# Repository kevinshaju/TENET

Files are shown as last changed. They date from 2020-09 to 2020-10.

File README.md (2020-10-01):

# __TENET__
WIRELESS DEVELOPMENT BOARD DESIGN

TENET is development board specifically designed for beginners and enthusiasts in the field of IoT and Robotics. At the heart of the board is the NINA-B302 microcontroller unit. The board also features the ESP-12F wireless chip for wireless connectivity. Incase if you're wondering how is it any different from other boards out there, then have a closer look at the design. TENET has an inbuilt DRV8833 motordriver which can be used to connect upto 2 motors without the need for any external shields. The board also has a Li-Po charging unit that can be used to power the board using a single cell Li-Po battery, which will come in handy while prototyping your next wireless robot.

The board also has quite a few sensors that you might need for your integrated Iot project. The details of all the features of the board are provided below:

1) 16 GPIO Headers
2) LSM9DS1-iNEMO Inertial Module
3) DRV8833 dual-H Bridge Motor Driver
4) LPS25HB Pressure Sensor
5) APDS-9960 Digital Proximity, Ambient Light, RGB and Gesture Sensor
6) HTS221 Capacitive digital sensor for relative humidity and temperature
7) ESP-12F WiFi Module

##  *"With TENET the only limit is your own imagination."*

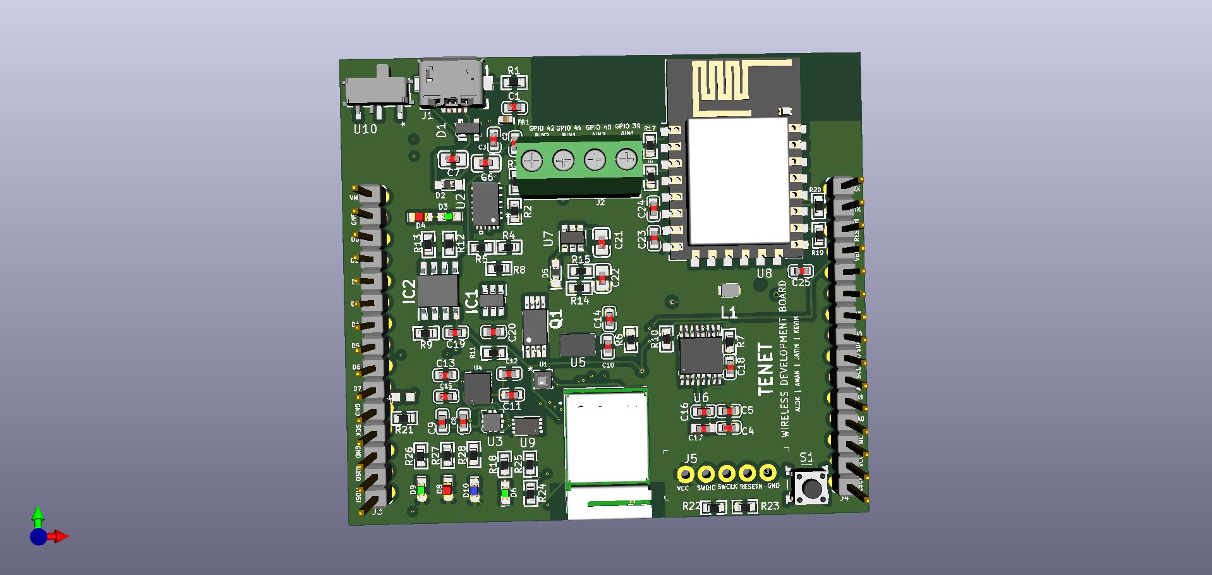
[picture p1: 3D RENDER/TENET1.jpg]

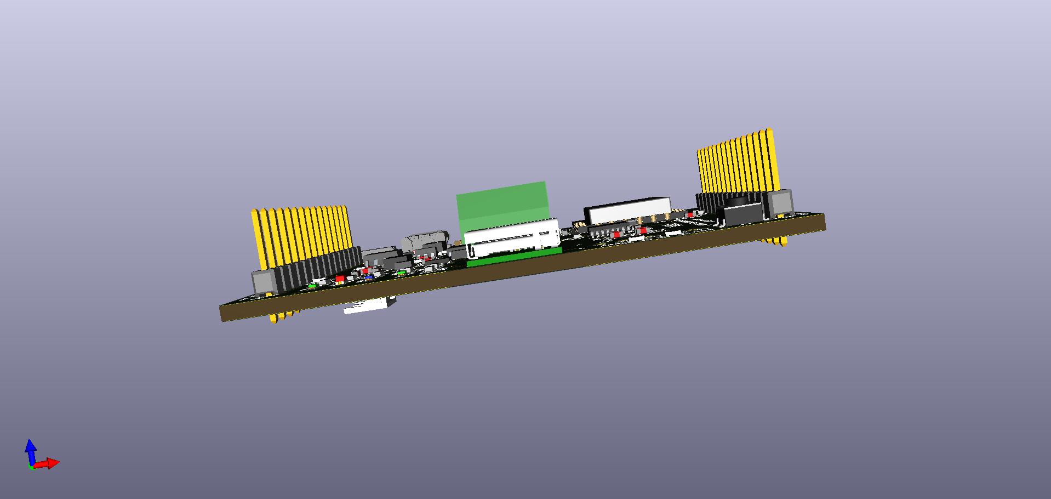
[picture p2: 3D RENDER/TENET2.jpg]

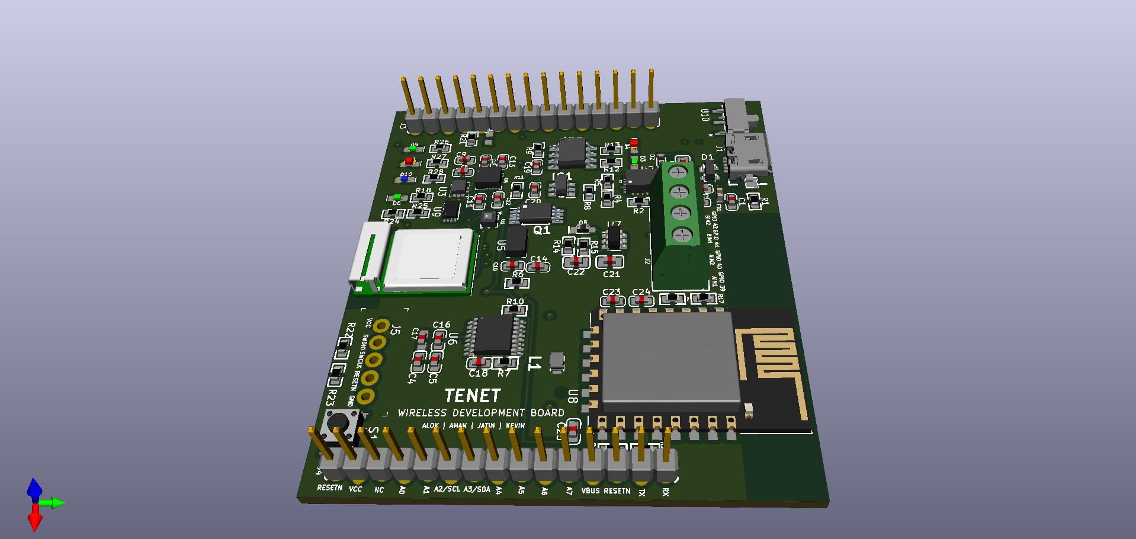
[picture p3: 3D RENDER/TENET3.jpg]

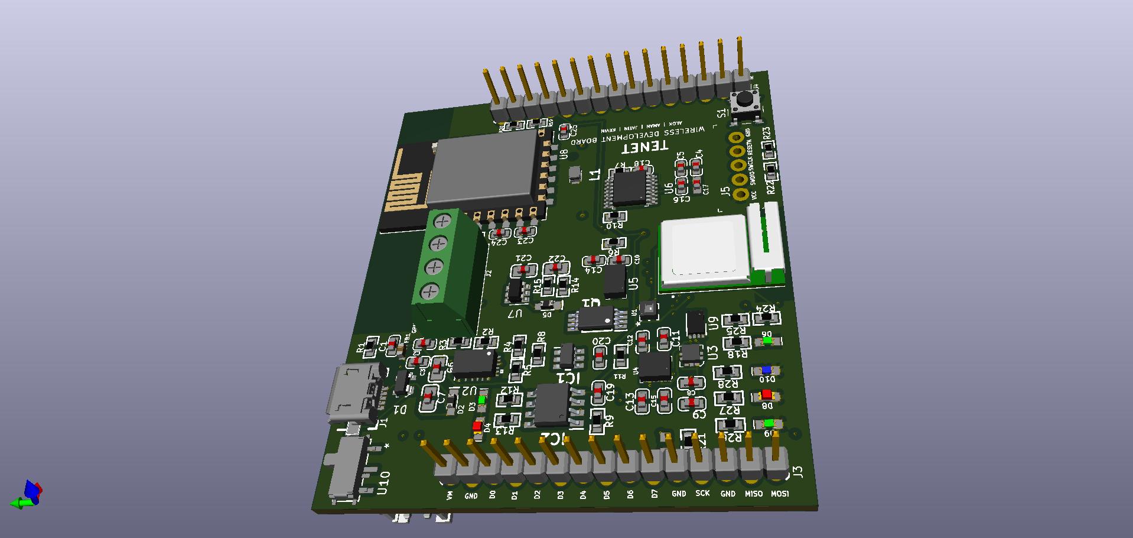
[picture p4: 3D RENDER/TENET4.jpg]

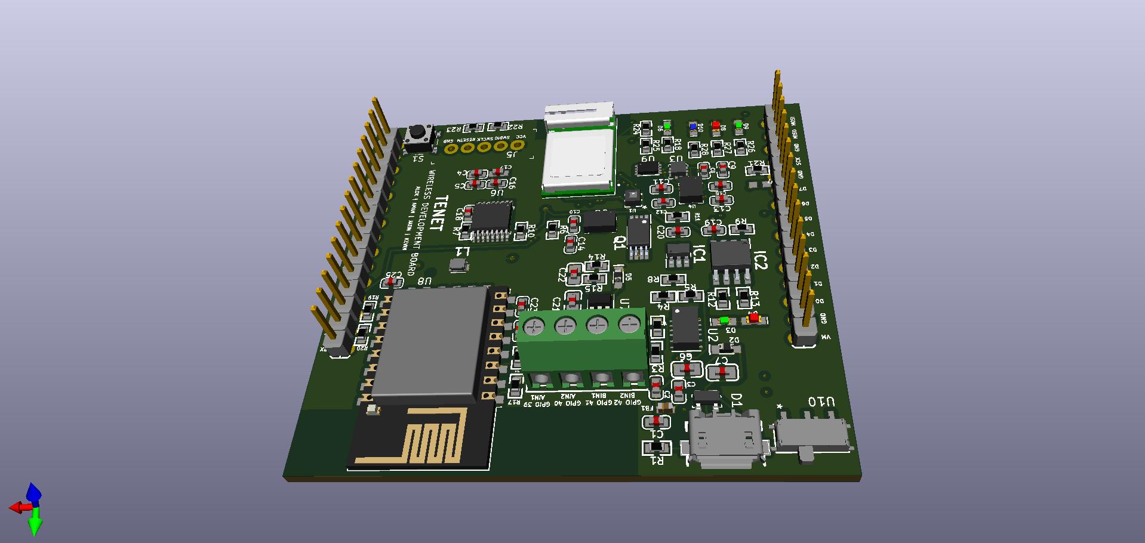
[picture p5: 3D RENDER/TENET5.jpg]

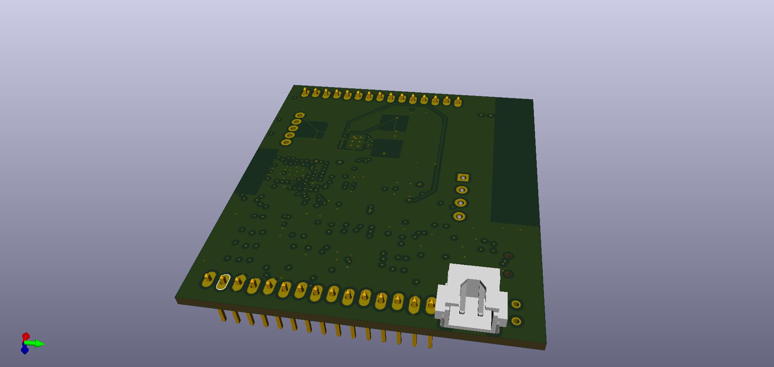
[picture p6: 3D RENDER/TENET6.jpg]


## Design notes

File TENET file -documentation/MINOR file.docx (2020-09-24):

a. Objective
b. Component required (rating and specification of each component)
c. Principle of working
d. Block diagram and description
e. Circuit diagram
f. Description of circuit and components
g. Advantage and disadvantage
h. application
i. result(photo)
j. Problem during designing
k. Cost of the project

Main processor used is nrf52840 is NINA B3X package

KEY FEATURES

Bluetooth 5 ready multi-protocol radio

- 2Mbps

- Long range

- Advertising extensions

- Improved coexistence (CSA #2)

IEEE 802.15.4 radio support

- Thread

- Zigbee

32-bit ARM Cortex-M4F @ 64MHz

Up to 111 dB link budget for Bluetooth long range mode Full-speed 12Mbs USB controller NFC Tag-A Software stacks available as downloads Application development independent of protocol stack Programmable output power from +8dBm to -20dBm -96dBm Sensitivity for Bluetooth low energy On-air compatible with nRF51, nRF24L and nRF24AP Series Arm CryptoCell CC310 crytographic security module High-precision RSSI Wide supply voltage range + 1.7V to 5.5V QSPI/SPI/2-wire/I²S/PDM/QDEC Programmable Peripheral Interface - PPI High speed SPI interface 32MHz Quad SPI interface 32MHz EasyDMA for all digital interfaces RAM mapped FIFO using EasyDMA 12bit/200K SPS ADC 128 bit AES/ECB/CCM/AAR co-processor Single-ended antenna output (on-chip balun) On-chip DC-DC buck converter Quadrature demodulator Regulated supply for external components up to 25mA

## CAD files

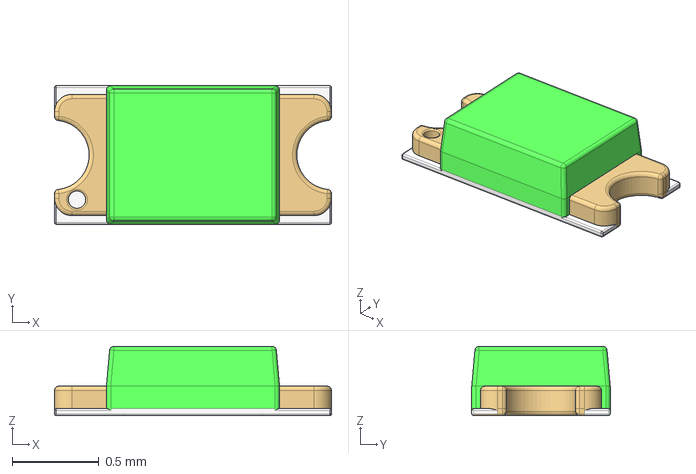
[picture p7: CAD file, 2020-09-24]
3D Libraries/LED Green SMD 0603 Würth 150060BS55040.stp
1.60 x 0.8 x 0.4 mm

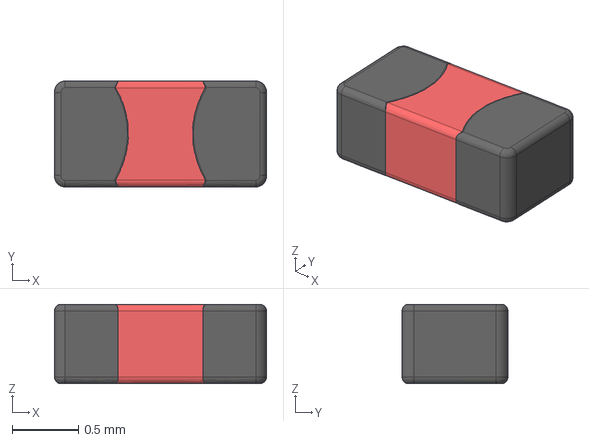
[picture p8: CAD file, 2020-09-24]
3D Libraries/Ceramic CAP0603.stp
1.60 x 0.8 x 0.6 mm

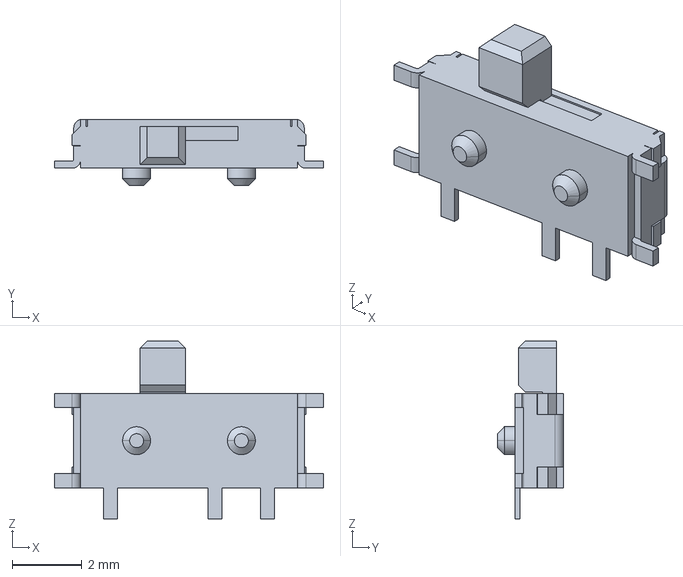
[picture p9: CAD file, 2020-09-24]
3D Libraries/c-1437575-2-b-3d.stp
7.70 x 1.90 x 5.09 mm

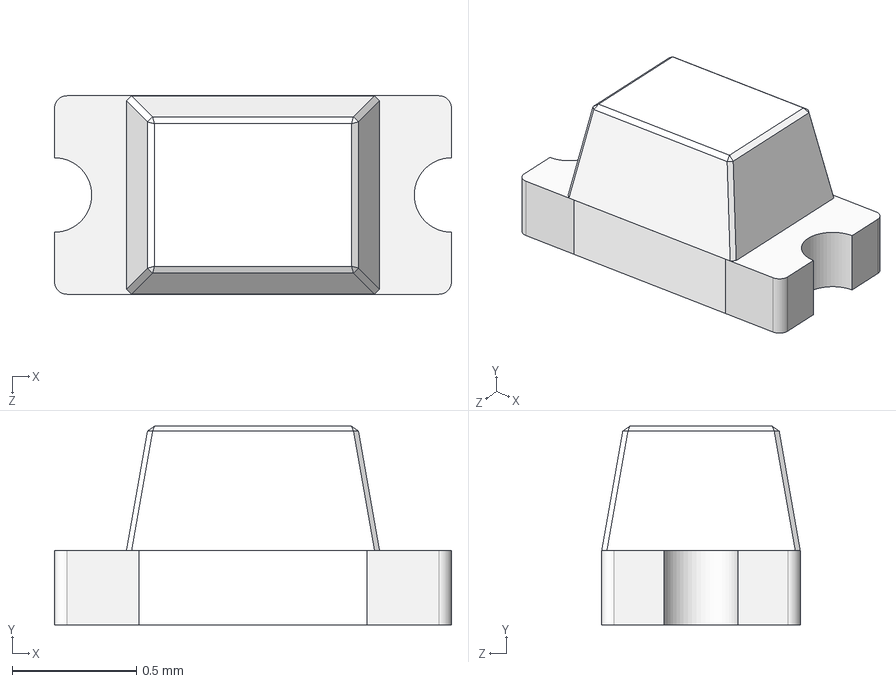
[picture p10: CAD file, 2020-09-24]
3D Libraries/0603 Chip SMD LED (1.6x0.8mm).STEP
1.60 x 0.8 x 0.8 mm

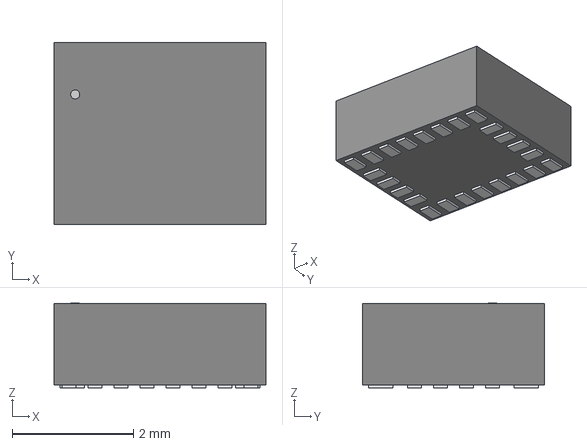
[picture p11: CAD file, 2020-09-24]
3D Libraries/LGA-24_3X3P5X1_STM-L.step
3.50 x 3.00 x 1.40 mm

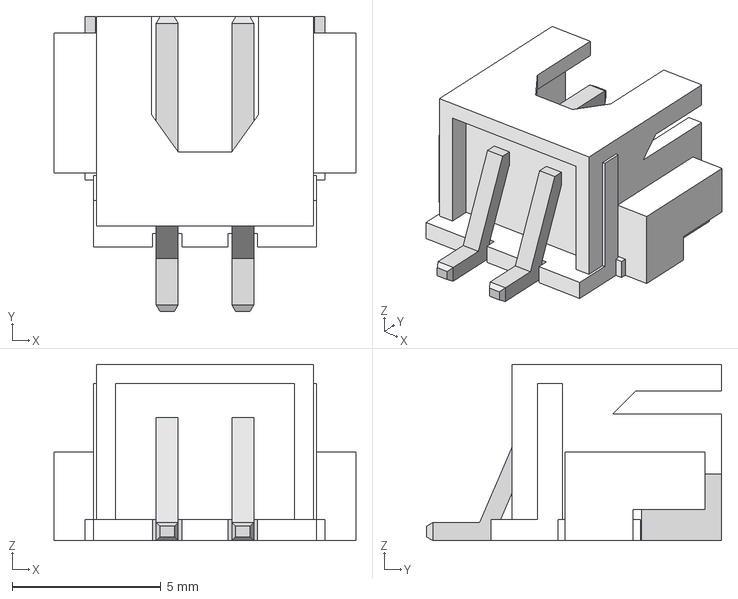
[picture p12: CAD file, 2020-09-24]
3D Libraries/JST - XH - SMD (R) - 2Pin - 2.54mm.stp
10.1 x 9.91 x 5.92 mm

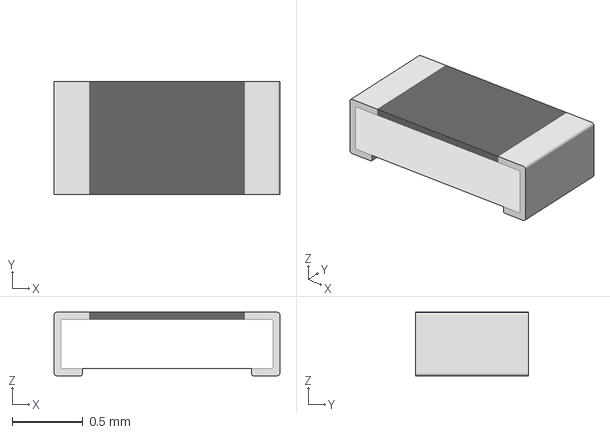
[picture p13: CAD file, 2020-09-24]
3D Libraries/RES0603.igs
1.60 x 0.8 x 0.45 mm

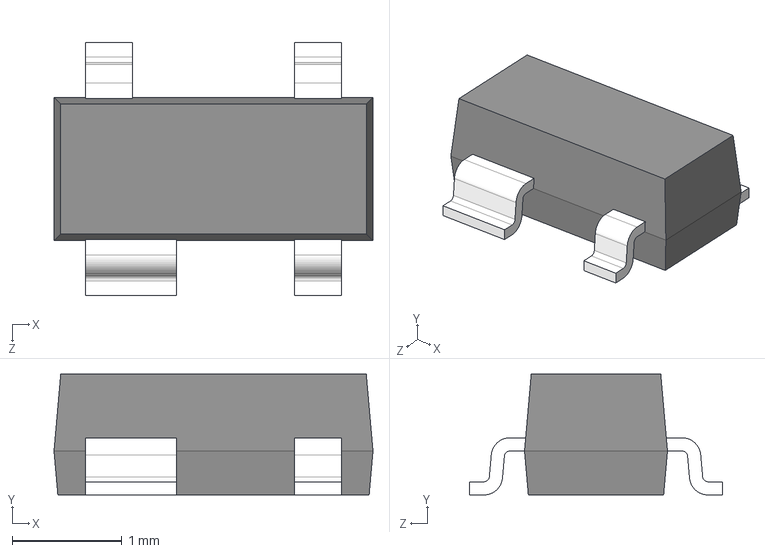
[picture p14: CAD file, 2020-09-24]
3D Libraries/PESD2ETH-AXR--3DModel-STEP-56544.STEP
2.90 x 1.10 x 2.30 mm

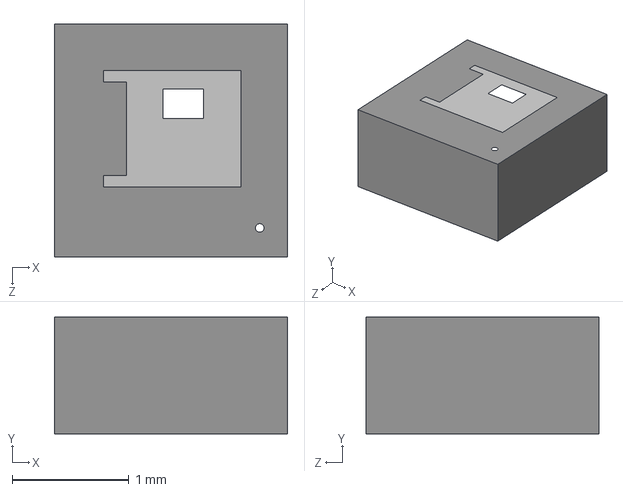
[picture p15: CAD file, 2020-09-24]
3D Libraries/HTS221TR--3DModel-STEP-56544.STEP
2.00 x 1.00 x 2.00 mm

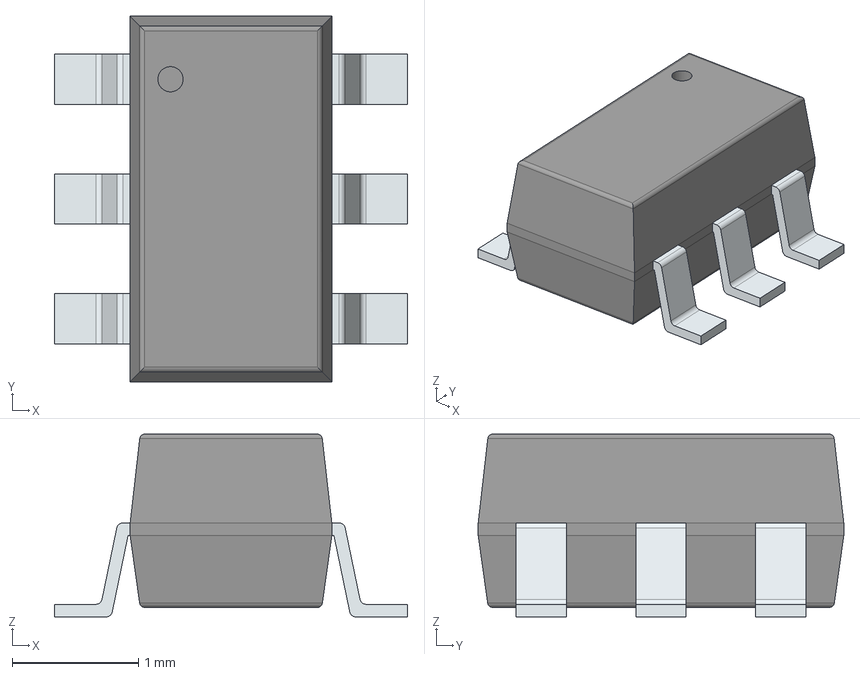
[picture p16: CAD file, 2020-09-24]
3D Libraries/FS312F-G.stp
2.80 x 2.90 x 1.45 mm
PinsArrayLR

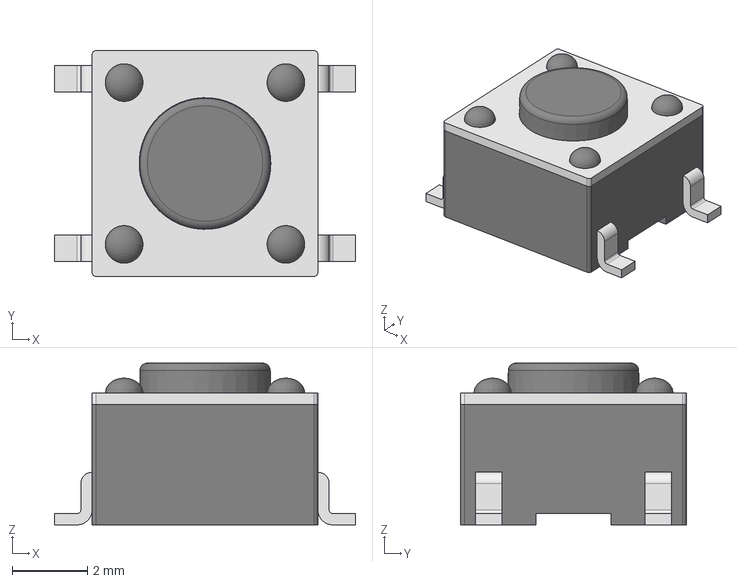
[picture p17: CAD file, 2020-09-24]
3D Libraries/TS6-SMT_H-4.3.step
8.00 x 6.00 x 4.30 mm

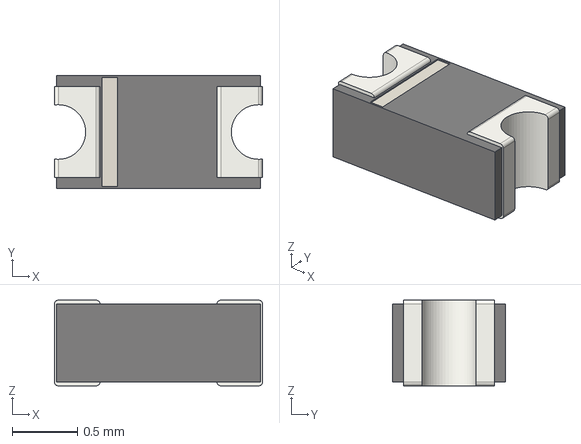
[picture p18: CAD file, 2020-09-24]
3D Libraries/D_0603_1608Metric.step
1.60 x 0.87 x 0.66 mm

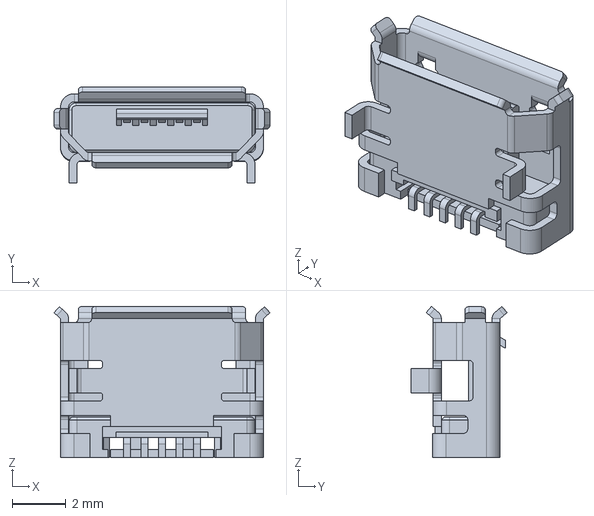
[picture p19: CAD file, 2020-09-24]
3D Libraries/c-2013499-1-e-3d.stp
8.00 x 3.57 x 5.60 mm

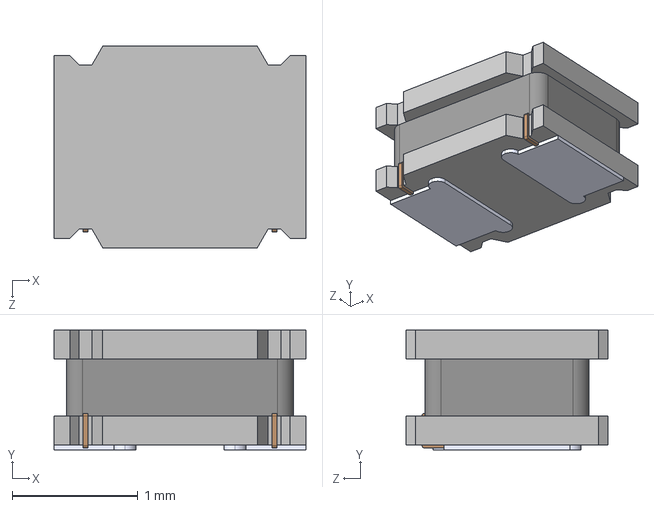
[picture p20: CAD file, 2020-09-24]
3D Libraries/LQH2MPZ220MGRL.STEP
2.00 x 0.95 x 1.60 mm

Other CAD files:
3D Libraries/LED Yellow SMD 0603 Würth 150060YS55040.stp
3D Libraries/LED Blue SMD 0603 Würth 150060BS55040.stp
3D Libraries/FS8205A--3DModel-STEP-56544.STEP
3D Libraries/Ceramic CAP0603.igs
3D Libraries/IND_BLM18_MUR.step
3D Libraries/LED Red SMD 0603 Würth 150060SS55040.stp
3D Libraries/MPM3610.STEP
3D Libraries/NINA-B3x2.STEP
3D Libraries/PWP16_2P31X2P46_TEX-L.step
3D Libraries/Pin Header 1x15 TH Pitch 2.54mm.stp
3D Libraries/QFN_DS-9930-M.step
3D Libraries/Screw Terminal Block 3.5mm 4-way.step
3D Libraries/TP4056-42-ESOP8.stp
3D Libraries/TS6-SMT_H-5.0.step
3D Libraries/c-4-1437565-2-v-3d.stp

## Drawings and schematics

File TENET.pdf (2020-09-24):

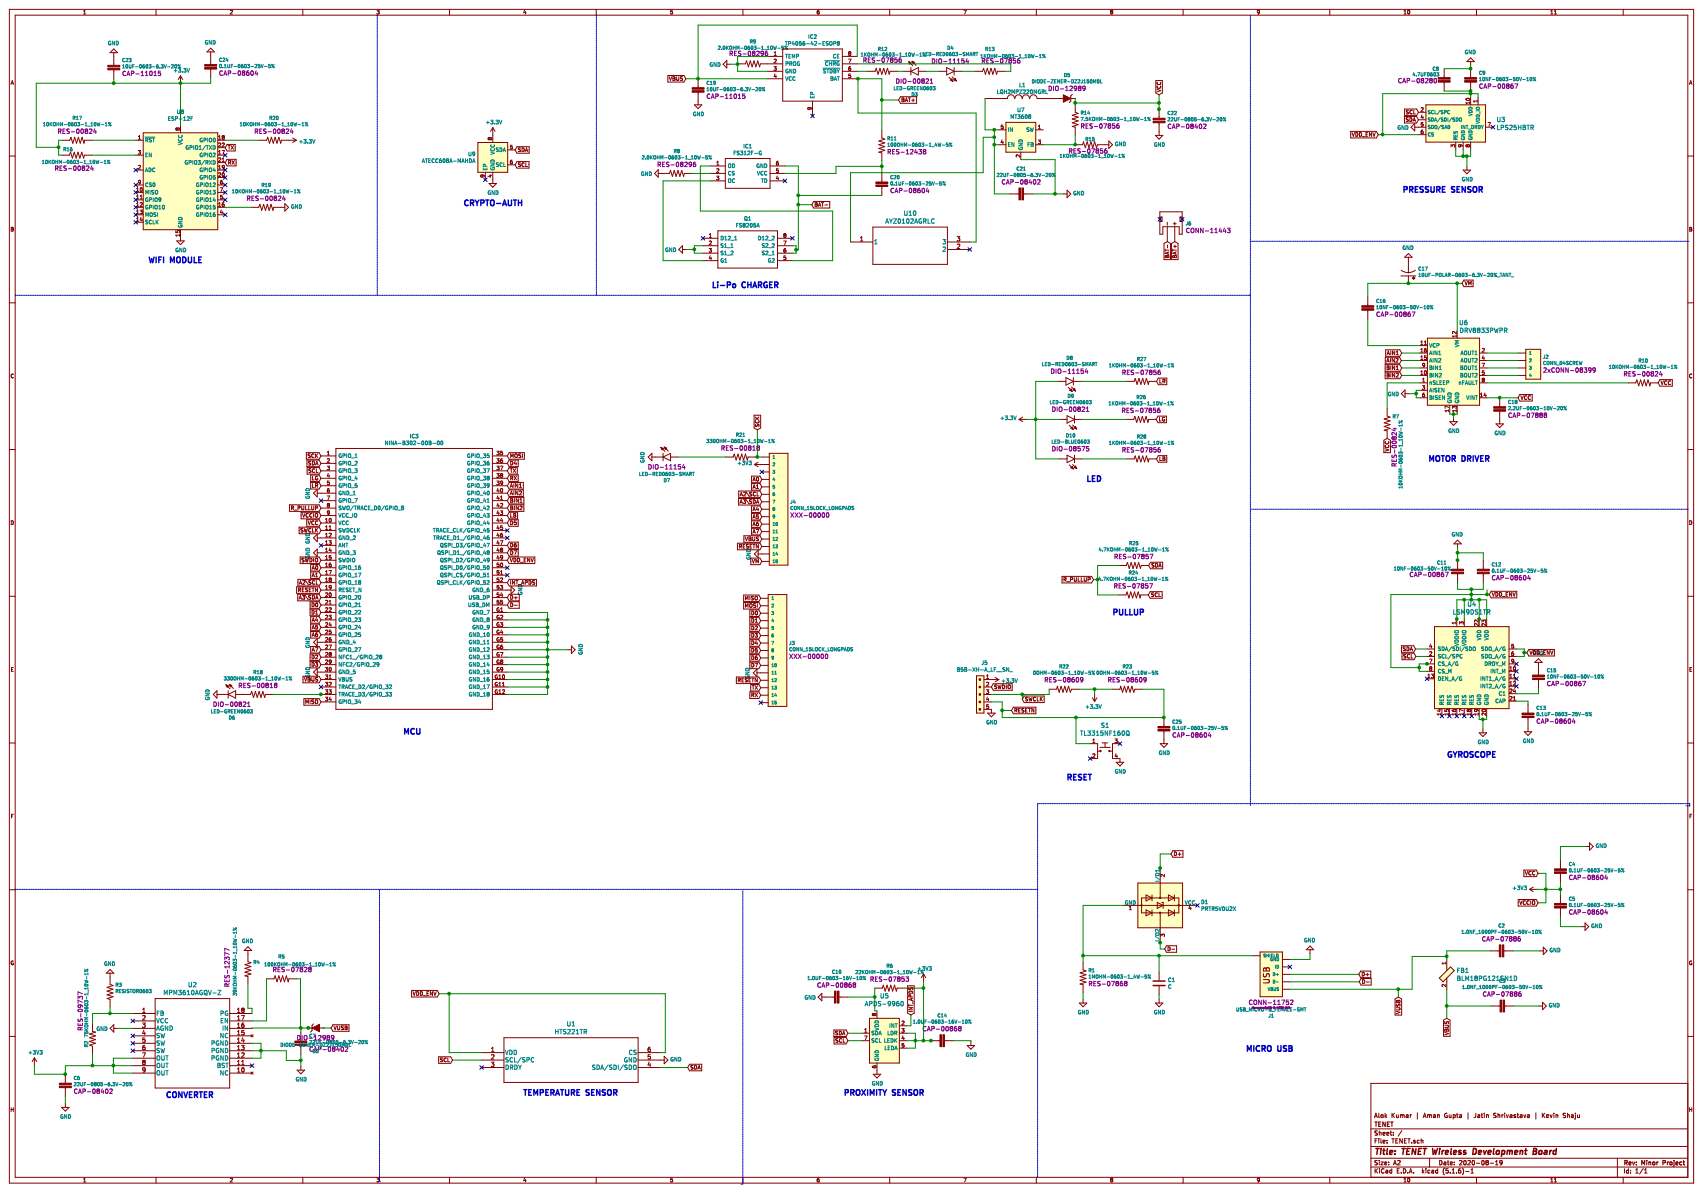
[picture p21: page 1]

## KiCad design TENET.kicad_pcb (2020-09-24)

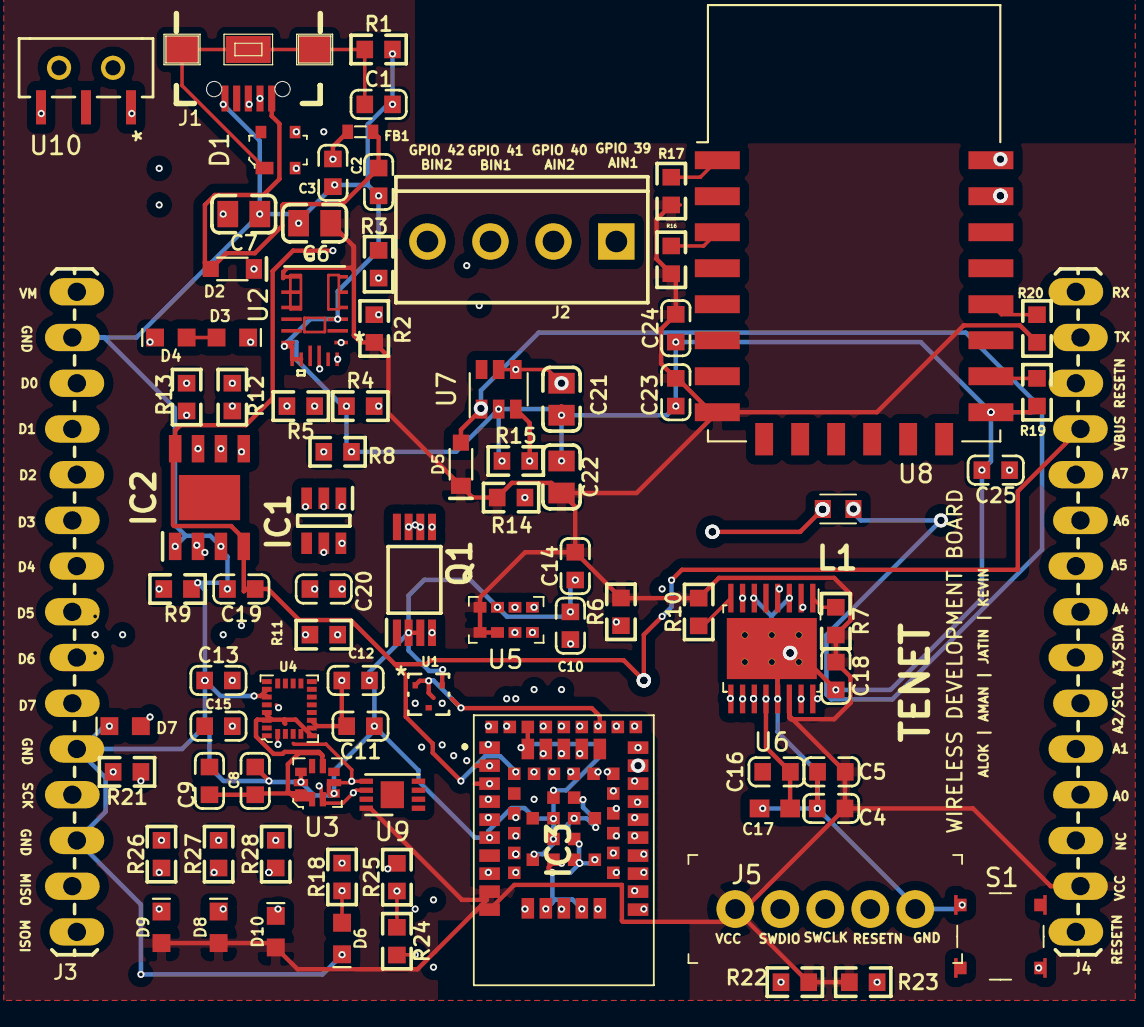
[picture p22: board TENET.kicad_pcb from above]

Board: 4 copper layers, 86 parts (1 on the bottom side), 83 nets.

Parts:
C1, C2, C3, C4, C5, C8, C9, C10, C11, C12, C13, C14, C15, C16, C18, C19, C20, C23, C24, C25: C_0603
C6, C7, C21, C22: C_0805
C17: 0603-POLAR
D1: TO-253-4
D2, D5: PANASONIC_SMINI2-F5-B
D3, D4, D6, D7, D8, D9, D10: LED-0603
FB1: BLM18PG121SN1D; 0603
IC1: SOT95P280X145-6N
IC2: SOIC127P600X175-9N
IC3: NINAB30200B00
J1: USB-B-MICRO-SMD
J2: SCREWTERMINAL-3.5MM-4
J3, J4: 1X15_LOCK_LONGPADS
J5: PinHeader_1x5_P2.5mm_Drill1.1mm
J6: JST-2-SMD
L1: LQH2MCN100K02L
Q1: SOP65P640X120-8N
R1, R2, R3, R4, R5, R6, R7, R8, R9, R10, R11, R12, R13, R14, R15, R16, R17, R18, R19, R20, R21, R22, R23, R24, R25, R26, R27, R28: R_0603
S1: Switch_Tactile_SMD_4.5x4.5mm_TL3315NF160Q
U1: HTS221TR
U2: MPM3610AGQV-Z
U3: LLGA-10_2.5x2.5mm_LPS25HB
U4: LGA-24_3x3.5mm_LSM9DS1
U5: Ambient_Prox_APDS-9960
U6: TSSOP-16-1EP_W4.40mm
U7: SOT-23-6
U8: ESP-12E
U9: DFN-8-1EP_3x2mm_P0.5mm_EP1.3x1.5mm
U10: AYZ0102AGRLC

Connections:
A0: IC3.16, J4.4
A1: IC3.17, J4.5
A2\SCL: IC3.18, J4.6
A3\SDA: IC3.20, J4.7
A4: IC3.23, J4.8
A5: IC3.24, J4.9
A6: IC3.25, J4.10
A7: IC3.27, J4.11
AIN1: IC3.39, U6.16
AIN2: IC3.40, U6.15
BAT+: IC2.5, J6.2, R11.1, U10.3
BAT-: C20.2, IC1.6, J6.1, Q1.6, Q1.7
BIN1: IC3.41, U6.9
BIN2: IC3.42, U6.10
D0: IC3.21, J3.3
D1: IC3.22, J3.4
D2: IC3.28, J3.5
D3: IC3.29, J3.6
D4: IC3.36, J3.7
D5: IC3.44, J3.8
D6: IC3.47, J3.9
D7: IC3.48, J3.10
D+: D1.2, IC3.54, J1.D+
D-: D1.3, IC3.55, J1.D-
GND: C1.2, C2.1, C3.1, C4.1, C5.2, C6.1, C7.1, C8.1, C9.1, C10.2, C11.1, C12.1, C13.1, C14.1, C15.1, C17.-, C18.2, C19.2, C21.1, C22.1, C23.2, C24.1, C25.2, D6.C, D7.C, IC2.1, IC2.3, IC3.6, IC3.12, IC3.14, IC3.26, IC3.30, IC3.53, IC3.G1, IC3.G2, IC3.G3, IC3.G4, IC3.G5, IC3.G6, IC3.G7, IC3.G8, IC3.G9, IC3.G10, IC3.G11, IC3.G12, J1.GND, J3.2, J3.11, J3.13, J5.5, Q1.2, Q1.3, R1.2, R3.1, R4.1, R8.1, R9.1, R15.1, R19.2, S1.4, U1.5, U2.3, U2.12, U2.13, U2.14, U3.3, U3.5, U3.8, U3.9, U4.19, U4.20, U5.6, U6.3, U6.6, U6.13, U6.17, U7.2, U8.15, U9.4
INT_APDS: IC3.52, U5.2
LB: IC3.43, R28.2
LG: IC3.4, R26.2
LR: IC3.5, R27.2
MISO: IC3.34, J3.14
MOSI: IC3.35, J3.15
unnamed: C1.1, D1.1, J1.SHIE, R1.1
unnamed: C7.2, D2.C, R5.2, U2.16
unnamed: C10.1, R6.1, U5.8
unnamed: C13.2, U4.21
unnamed: C15.2, U4.24
unnamed: C16.2, U6.11
unnamed: C20.1, IC1.5, R11.2
unnamed: C21.2, L1.1, U7.4, U7.5, U10.1
unnamed: D3.A, D4.A
unnamed: D3.C, R12.2
unnamed: D4.C, R13.1
unnamed: D5.A, L1.2, U7.1
unnamed: D6.A, R18.1
unnamed: D7.A, R21.1
unnamed: D8.C, R27.1
unnamed: D9.C, R26.1
unnamed: D10.C, R28.1
unnamed: IC1.1, Q1.5
unnamed: IC1.2, R8.2
unnamed: IC1.3, Q1.4
unnamed: IC2.2, R9.2
unnamed: IC2.6, R12.1
unnamed: IC2.7, R13.2
unnamed: IC3.33, R18.2
unnamed: J2.1, U6.2
unnamed: J2.2, U6.4
unnamed: J2.3, U6.7
unnamed: J2.4, U6.5
unnamed: R2.2, R3.2, U2.1
unnamed: R4.2, U2.18
unnamed: R5.1, U2.17
unnamed: R7.1, U6.1
unnamed: R10.1, U6.8
unnamed: R14.2, R15.2, U7.3
unnamed: R16.2, U8.3
unnamed: R17.2, U8.1
unnamed: R19.1, U8.16
unnamed: R20.1, U8.18
RESETN: C25.1, IC3.19, J4.1, J4.13, J5.4, R23.1, S1.1
RX: IC3.38, J4.15, U8.21
R_PULLUP: IC3.8, R24.1, R25.1
SCK: IC3.1, J3.12, R21.2
SCL: IC3.3, R24.2, U1.2, U3.2, U4.2, U5.7, U9.6
SDA: IC3.2, R25.2, U1.4, U3.4, U4.4, U5.1, U9.5
SWCLK: IC3.11, J5.3, R22.2
SWDIO: IC3.15, J5.2
TX: IC3.37, J4.14, U8.22
VBUS: C3.2, C19.1, FB1.2, IC2.4, IC2.8, IC3.31, J4.12
VCC: C4.2, C5.1, C6.2, C14.2, C18.1, C22.2, C23.1, C24.2, D5.C, D8.A, D9.A, D10.A, IC3.9, IC3.10, J4.2, J5.1, R2.1, R6.2, R7.2, R10.2, R14.1, R16.1, R17.1, R20.2, R22.1, R23.2, U2.7, U2.8, U2.9, U5.3, U5.4, U5.5, U6.14, U8.8, U9.8
VDD_ENV: C8.2, C9.2, C11.2, C12.2, IC3.49, U1.1, U1.6, U3.1, U3.6, U3.10, U4.1, U4.3, U4.5, U4.6, U4.7, U4.8, U4.22, U4.23
VM: C16.1, C17.+, J3.1, U6.12
VUSB: C2.2, D2.A, FB1.1, J1.VBUS

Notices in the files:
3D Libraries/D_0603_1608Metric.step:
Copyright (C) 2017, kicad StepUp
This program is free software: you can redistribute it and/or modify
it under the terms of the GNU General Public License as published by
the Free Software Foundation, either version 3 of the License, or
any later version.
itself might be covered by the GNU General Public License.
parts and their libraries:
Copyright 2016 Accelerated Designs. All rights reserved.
